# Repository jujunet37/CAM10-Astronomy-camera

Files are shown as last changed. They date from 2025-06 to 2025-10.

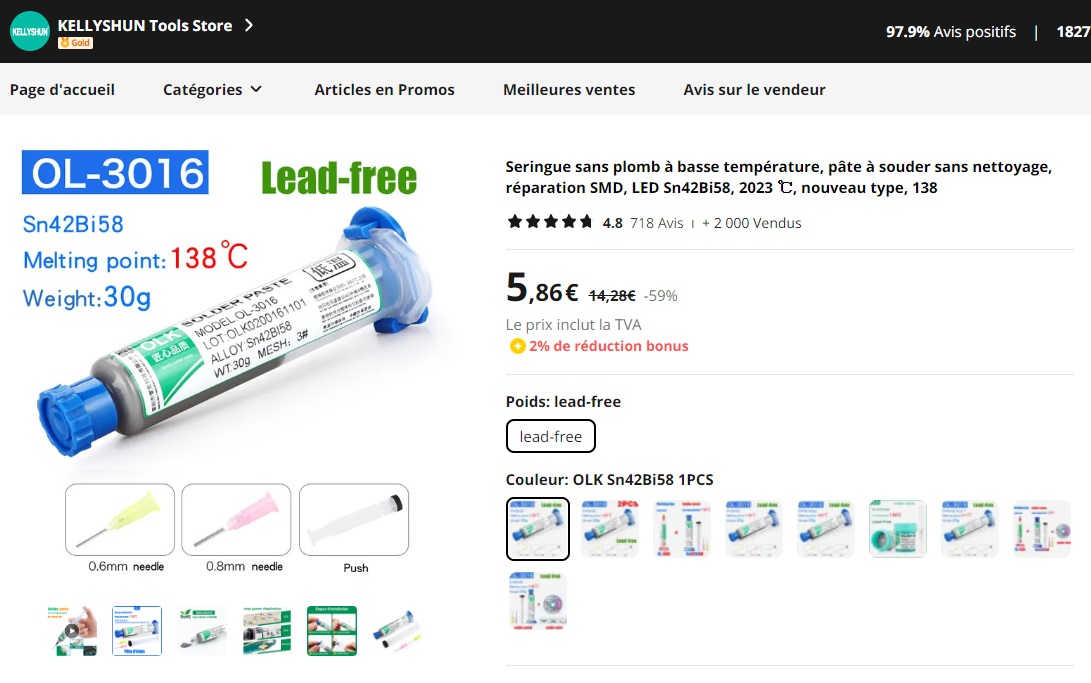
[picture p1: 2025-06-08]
Cam 10 ASCOM version/Component list/Other Stuff/Solder_paste.jpg

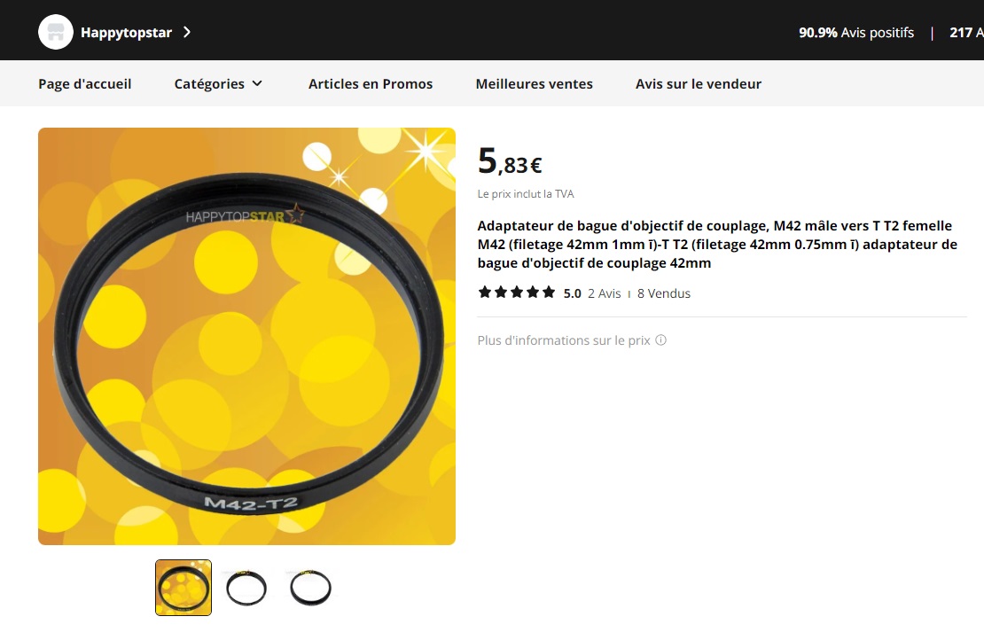
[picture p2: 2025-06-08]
Cam 10 ASCOM version/Component list/bague_M42_T2.jpg

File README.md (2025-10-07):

# CAM10-Astronomy-camera

## This repository contains all files needed to build two differents astronomy monochrome Cam10 cameras with a resolution of 1280x1024. Original wiring diagram was made by grim from Astroclub.kiev.ua.
CAUTION : For Autoguiding use the ASCOM version. The COM version is only for standalone use with the viewer.

## UPDATE 07/10/2025 :

The driver has been updated to work with PHD2. The workaround with PHD1 explained in the video is not necessary anymore. 
Driver version 0.5 didn't work because camera settings woulnd't open, and camera settings button was grayed out.
I made modifications on this driver to open the camera settings on loading. So now you can tune the image directly in PHD2.
Enjoy !

Note : I noticed my anti virus show a false positive on my mini PC (Windows Defender). It's normal with ASCOM unsigned drivers.
You can put it in white list to install if you have the message.

# Cam10 COM version :

Description : This camera can be use for planetary Imaging, there is no ASCOM driver. The viewer communicate with a virtual serial COM port. Using the pcb provided by grim I made a 3D printed enclosure for this camera. All parts needed are in the folder.

## Folders :

- Cam 10 COM Viewer : The viewer, it's a standalone viewer developped by grim to capture images on jpg, bmp, fit and ser formats. ROI capability and exposure / ISO settings. Gain/offset/delta/timer parameters.
- Components list : I provided the list of elements, with screen captures to avoid dead links, so you can easyly retrieve the parts needed.
- Firmware : The firmware and the utility to flash it on the camera (ST-LINK)
- PCB Gerber File : The Gerber file to make the PCB
- STL files Cam10 COM version : The stl files to print the enclosure

# Cam10 ASCOM version :

Description : This camera can be used for both planetary imaging and autoguiding. A viewer can be used for standalone acquisition. An ASCOM driver is provided, works with ASCOM 6.2. I used the original wiring from grim and corrected a missing track. I made a new corrected PCB with mounting holes to install a heatsink. I also made an 3D printed enclosure.

## Folders :

- ASCOM driver : This is the ascom driver to make it communicate with all astronomy softwares (Sharpcap, OpenNebulosity, PHD2). Version 0.5
- Components list : I provided the list of elements, with screen captures to avoid dead links, so you can easyly retrieve the parts needed.
- Firmware + MPROG : This is the firmware and the programming utility for flashing the FT2232 chip
- FT2232 Driver : Drivers for Windows for the FT2232. I provided 2 drivers, you can check for updates on FTDI website, type FT2232HL and install lastest drivers. WARNING : Since several years FTDI brick non genuine chips. If you purchased your chip on an official reseller, you can update to last driver. If your chip comes from Aliexpress or EBay, be careful about that, if you have any doubt, install the 2.08 provided driver.
- Old ASCOM Platform : This is the old ASCOM platform that works with this camera, not tested with newer versions.
- PCB Gerber file : The Gerber file to make the PCB
- Schema : Original diagram by grim
- STL Files CAM 10 ASCOM : The stl files to print the enclosure
- Viewer Source and Exec : Viewer souce files and main executable.

## Softwares folder : 

- This is PHD first version (very hard to found on the web). Use for the workaround to make the ascom parameter works in PHD2. Look at YouTube video link below.

Links :

Youtube tutorials :

French : https://www.youtube.com/watch?v=oHPourlEOjQ
English : https://www.youtube.com/watch?v=FNpK9c-Fqkc

Astroccd : http://astroccd.org/
Ukrainian Astropolis topic : https://www.astroclub.kiev.ua/forum/index.php?PHPSESSID=su8vh9h1n0l7lrnate4rmb50v5&topic=28929.0

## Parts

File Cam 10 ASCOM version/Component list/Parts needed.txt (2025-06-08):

Part					Number		Ref

Spring					3		Aliexpress : Honcky Shop Store 0.4mm, 10mm, 3mm 65Mn
USB cable A to B Male - Male		1		Aliexpress : QGeeM Official Store
Screw 10mmx1.6mm, washer and nut	3		Aliexpress : CLOXY Hardware Store
Copper stem 8x100			1		Aliexpress : Super 1 Store
Heatsink				1		Aliexpress : MoreSuns CustomElectronic Product Store
M42-EOS Ring				1		Aliexpress : Hension Co, Ltd Store

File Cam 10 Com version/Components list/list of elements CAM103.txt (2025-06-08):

Number	Size          	Value            Ref Farnell/Aliexpress
_____________________________________________

C1   	CAP_0603     	105   1µF  
C3   	CAP_1206     	107   100µF
C4   	CAP_1206     	107   100µF
C5   	CAP_0603     	105   1µF
C6   	CAP_0603     	105   1µF 
C7   	CAP_0603     	105   1µF  
C8   	CAP_0603     	105   1µF
C9   	CAP_0603     	105   1µF    
C31  	CAP_0603     	8p2   8.2pF           
C32  	CAP_0603     	8p2   8.2pF           
C33  	CAP_0603     	105   1µF             
C34  	CAP_0603     	105   1µF             
C36  	SIZE D       	107   100µF           
C39  	CAP_0603     	105   1µF           
R1   	RES_0603     	103   10kO           
R2   	RES_0603     	333   33kO      
R3   	RES_0603     	103   10kO         
R14  	RES_0603     	222   2.2kO      
R15  	RES_0603     	106   10MO           
R16  	RES_0603     	123   12kO  
U1   	MT9M001C12STM                 
U2   	Micro JST 1.25 3 pin
U3   	Micro JST 1.25 4 pin
U4   	TESTPOINT2   	     
U5   	STM32F446RCT6	            
U6   	LM1117-3.3   	               
U8   	USB3300      	               
Y2   	24MTSX             

Bill of mats :

Number	Size          	Value        Number    Ref Farnell/Aliexpress

C3   	CAP_1206     	107   100µF   	2	4128589      
C31  	CAP_0603     	8p2   8.2pF     2	3790636                
C33  	CAP_0603     	105   1µF       9	2112858      
C36  	SIZE D       	107   100µF     1	197348         
R1   	RES_0603     	103   10kO      2	2502926     
R2   	RES_0603     	333   33kO      1	3994549       
R14  	RES_0603     	222   2.2kO     1	3994460
R15  	RES_0603     	106   10MO	1	9238964         
R16  	RES_0603     	123   12kO 	1	2333583
U1   	MT9M001C12STM                 	1	Aliexpress : Small Li Sen Store
U2   	Micro JST 1.25 3 pin		1	Aliexpress : More Connectors Store
U3   	Micro JST 1.25 4 pin  	     	1	Aliexpress : More Connectors Store
U5   	STM32F446RCT6	            	1	Aliexpress : EC-Buying Ali Store
U6   	LM1117-3.3   	               	1	Aliexpress : Shop130245 Store
U8   	USB3300      	               	1	Aliexpress : WANXINDA Official Store
Y2   	24MTSX         			1	2853960   
USB Connector				1	3490505   
Screw 10mmx1.6mm, washer and nut	6	Aliexpress : CLOXY Hardware Store
T2 ring					1	Aliexpress : LING-SHI Store
Heatsink				1	Aliexpress : Cooltex Thermal Management Store
Glass					1	Aliexpress : SZ-TOP Store
STlink USB Key				1	Aliexpress : TENSAR ROBOT GREAT WALL Store
USB Cable A to B Male - Male		1	Aliexpress : QGeeM Offcial Store

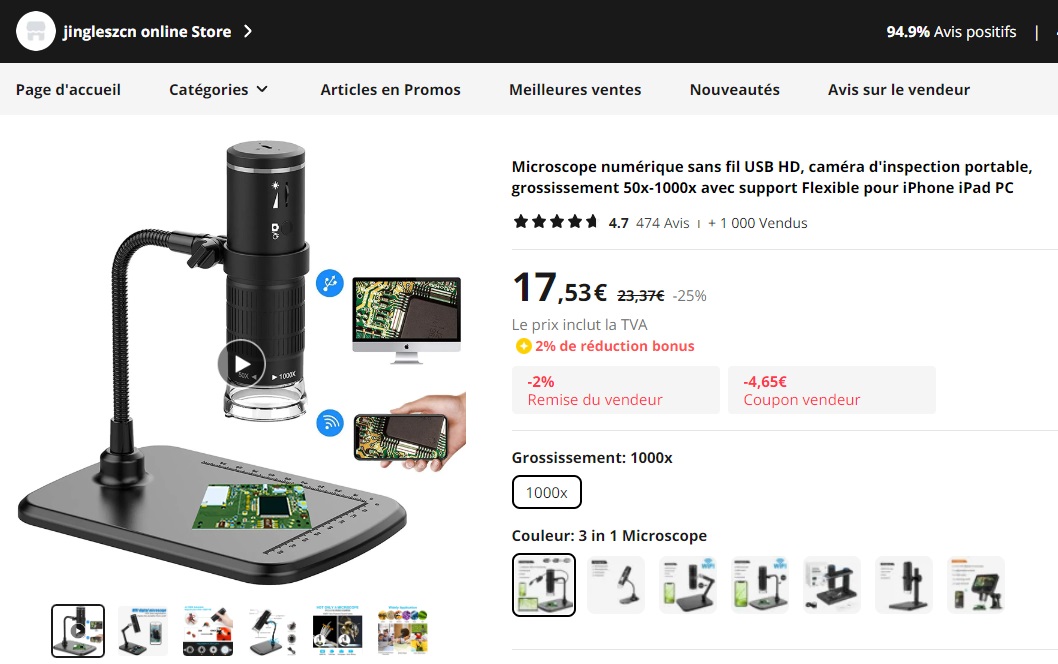
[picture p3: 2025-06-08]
Cam 10 Com version/Components list/Other Stuff/Microscope.jpg

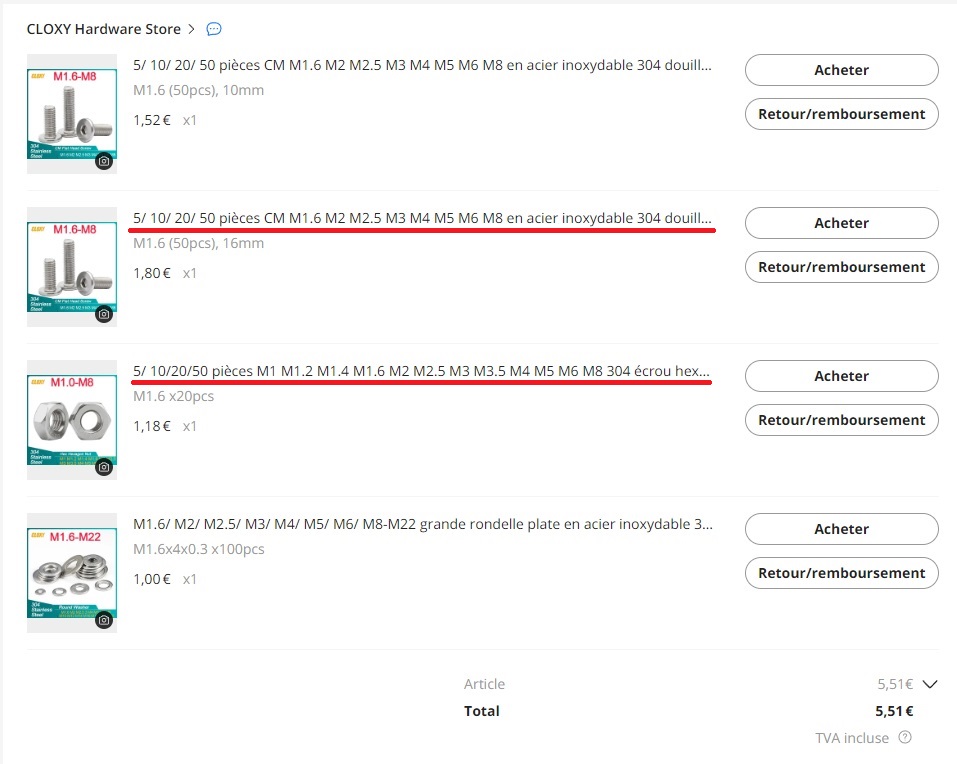
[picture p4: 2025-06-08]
Cam 10 ASCOM version/Component list/Screw ASCOM.jpg

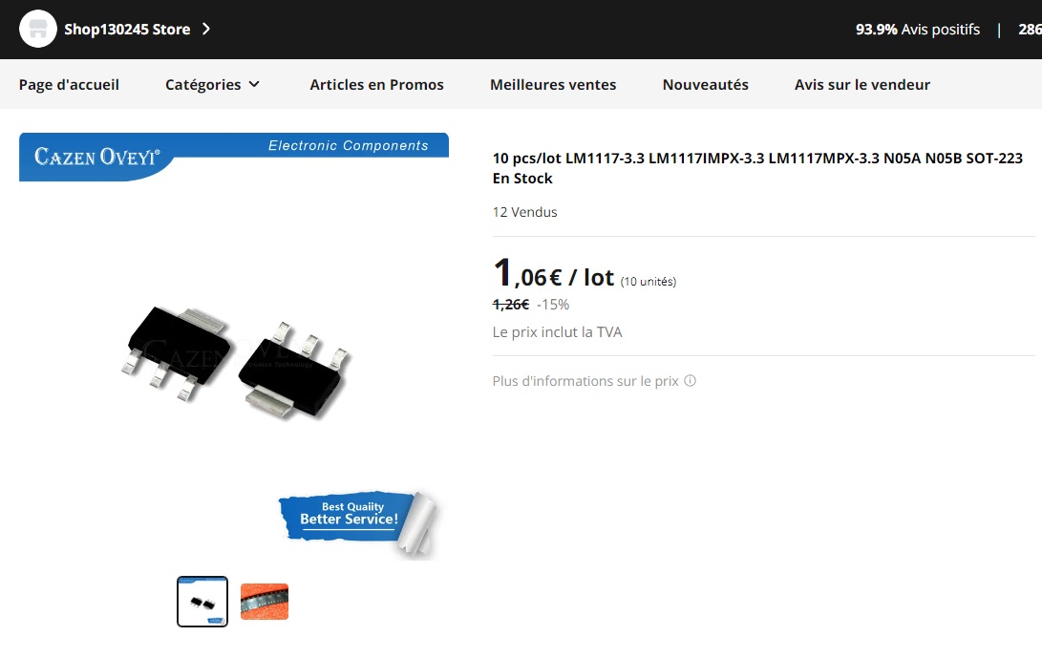
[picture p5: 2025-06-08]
Cam 10 Com version/Components list/LM1117-3.3.jpg

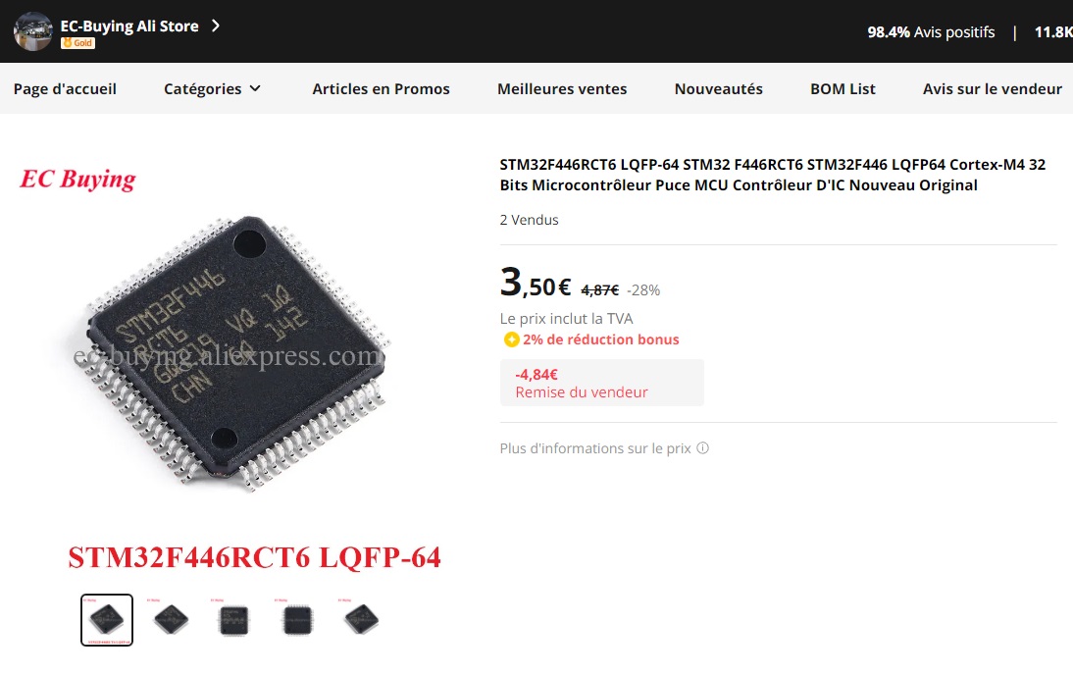
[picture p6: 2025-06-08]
Cam 10 Com version/Components list/STM32.jpg

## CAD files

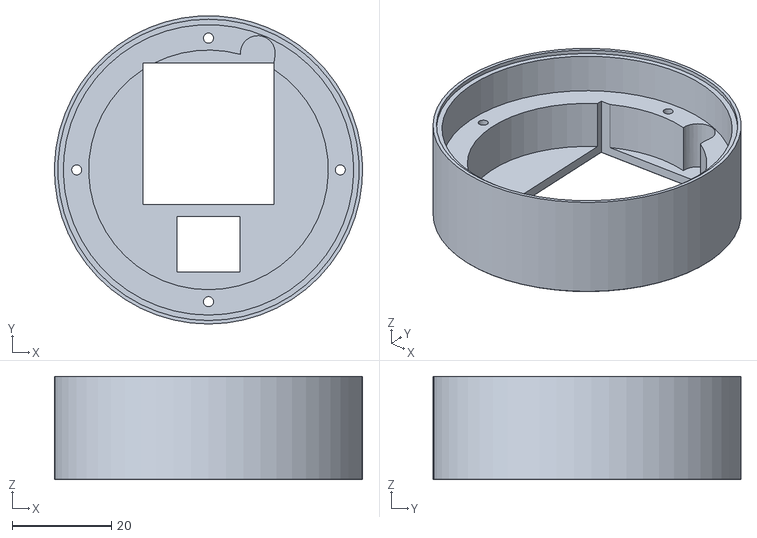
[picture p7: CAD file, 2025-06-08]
Cam 10 ASCOM version/STL Files CAM 10 ASCOM/CAM10_2-Corps.stl
62.0 x 61.9 x 20.8

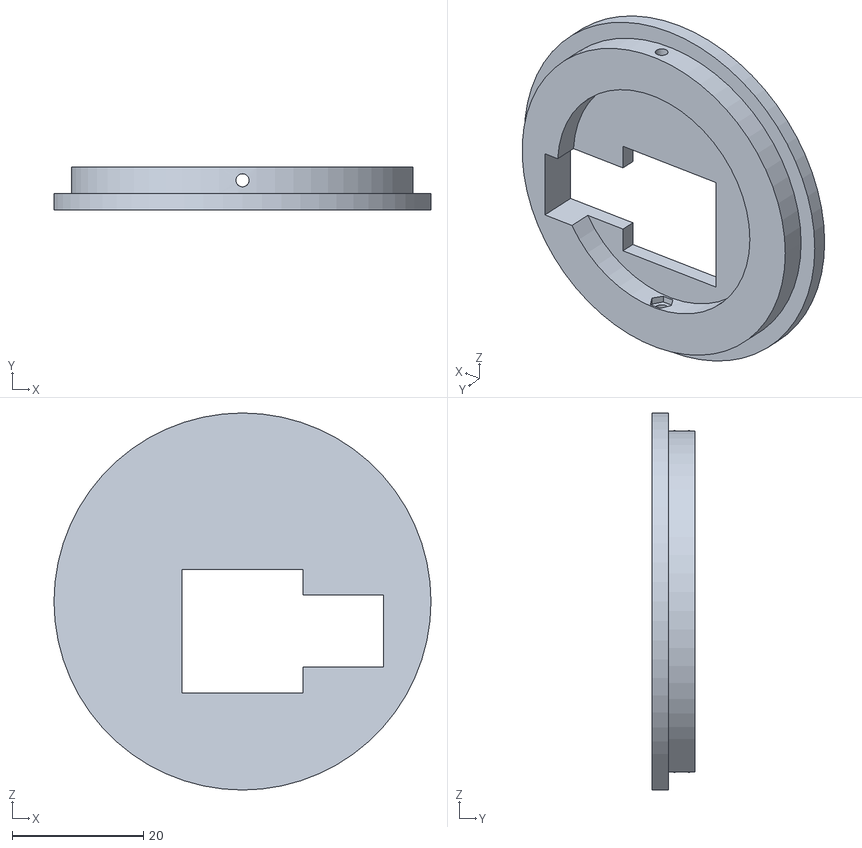
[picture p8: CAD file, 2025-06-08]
Cam 10 Com version/STL files Cam10 COM version/Cam10_ComVersion_Couvercle-Body.stl
57.4 x 6.50 x 57.4

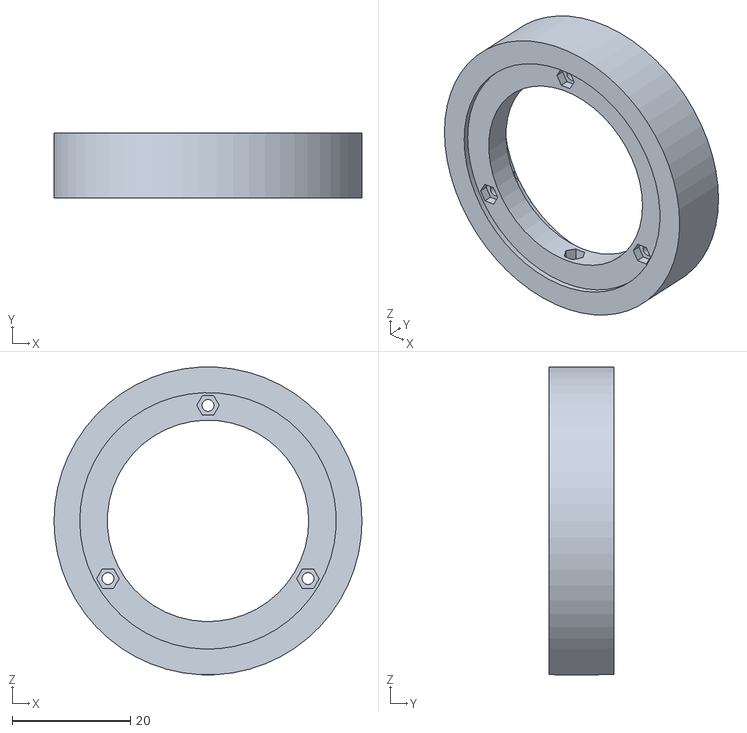
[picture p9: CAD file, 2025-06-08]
Cam 10 Com version/STL files Cam10 COM version/Cam10_ComVersion-Body.stl
52.0 x 11.0 x 52.0

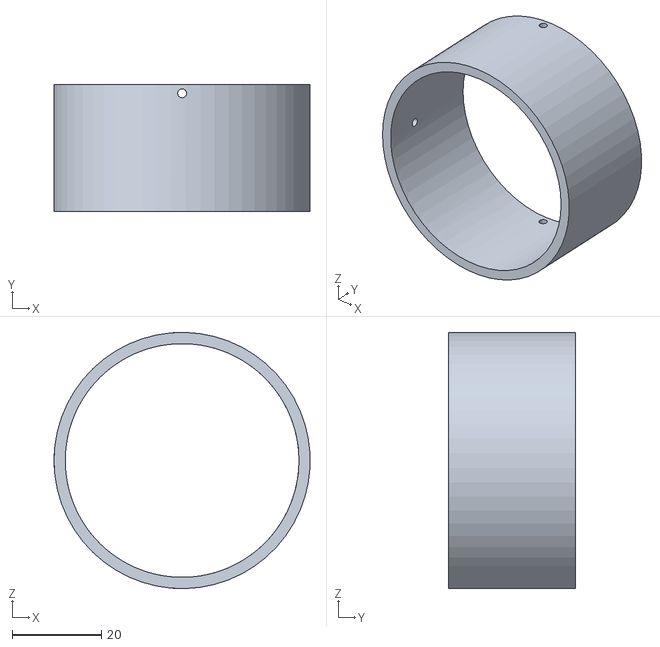
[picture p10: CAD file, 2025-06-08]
Cam 10 Com version/STL files Cam10 COM version/Cam10_ComVersion_Body-Body.stl
57.4 x 28.5 x 57.4

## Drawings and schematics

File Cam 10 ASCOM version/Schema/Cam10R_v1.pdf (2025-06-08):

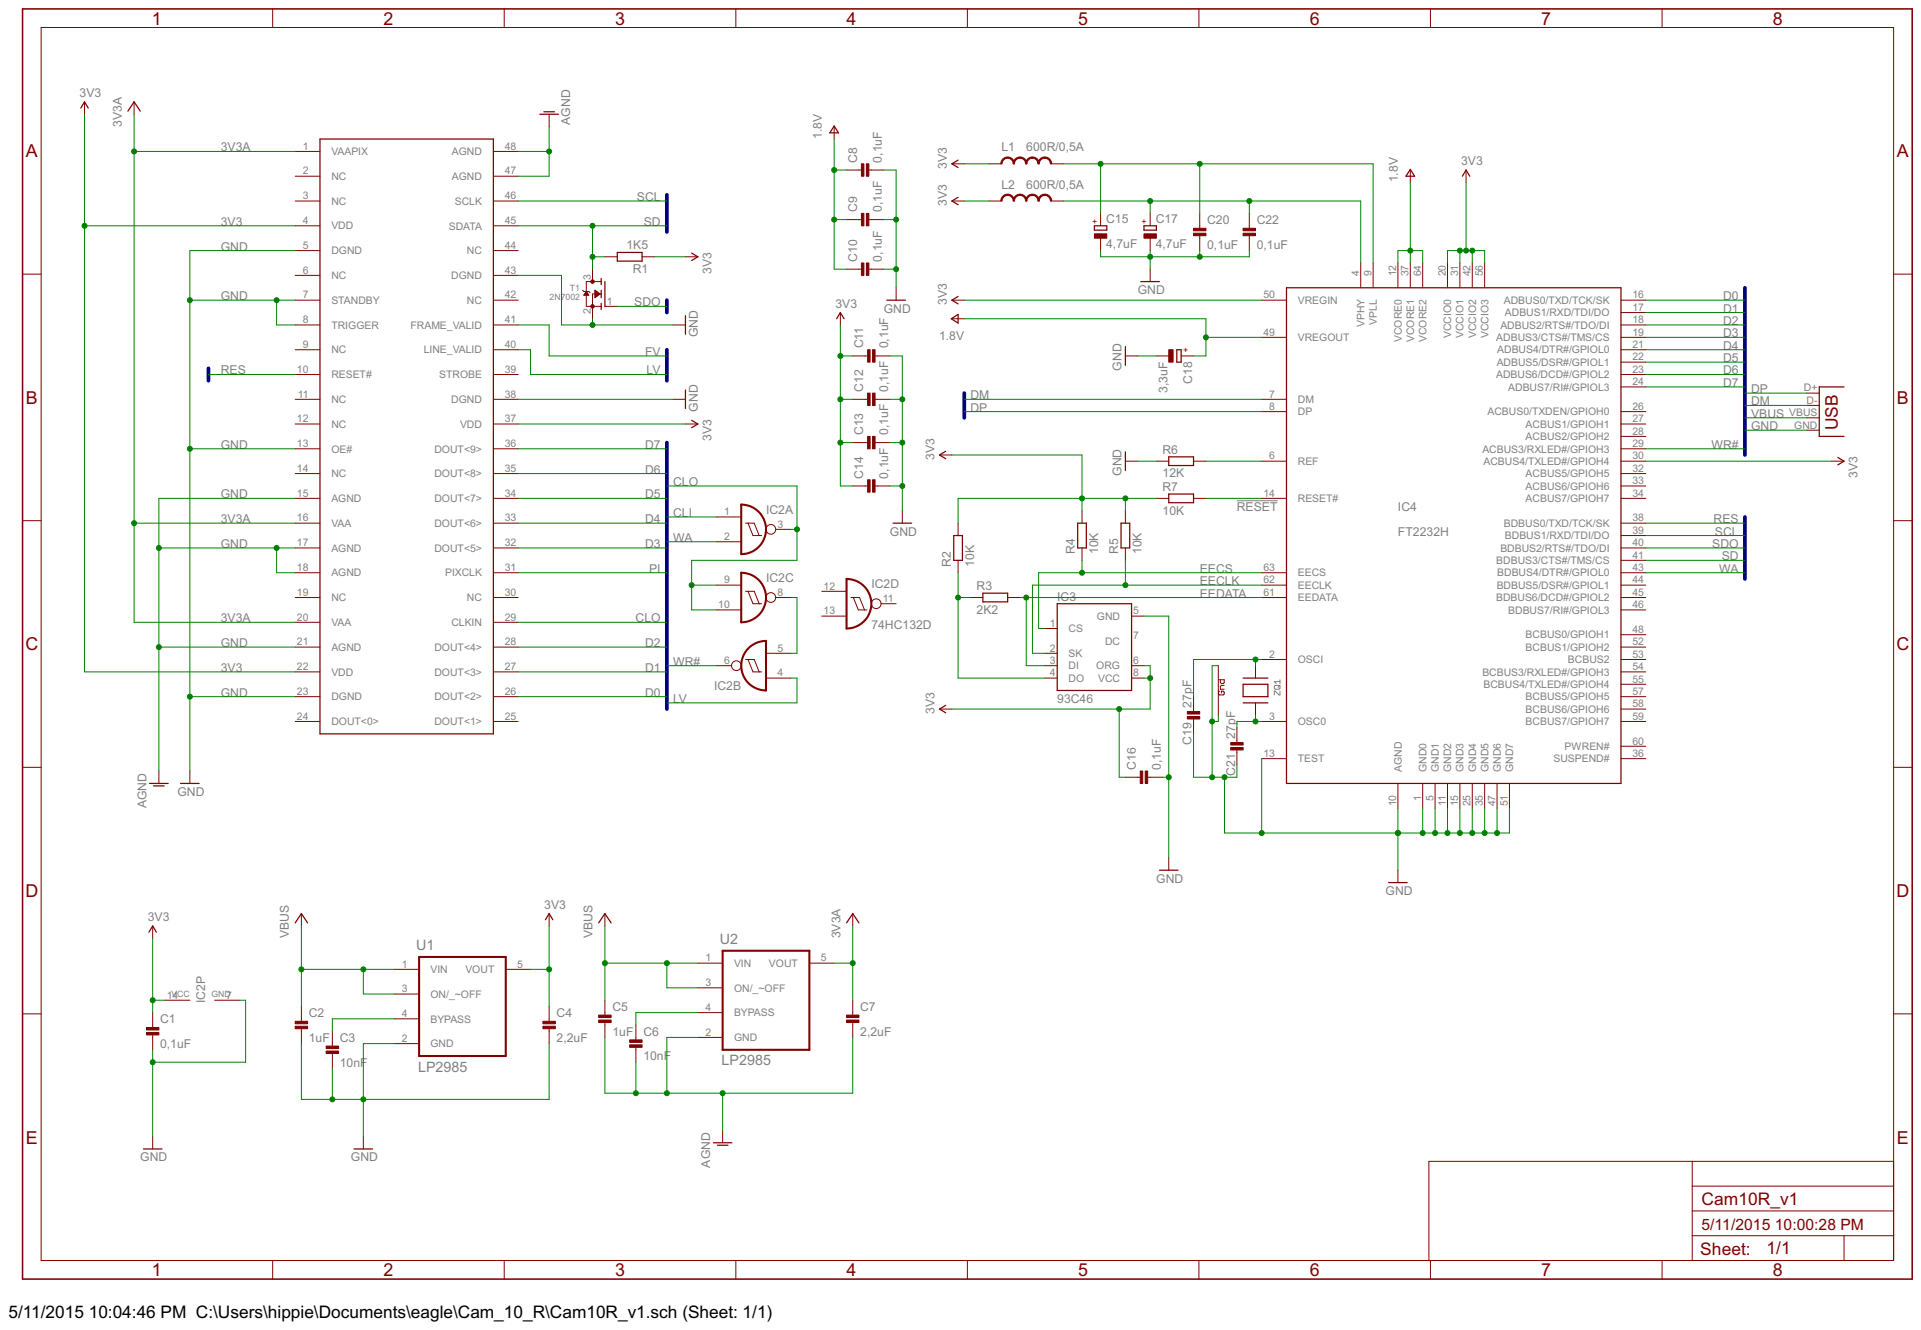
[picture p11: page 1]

GND | | 44 SDATA 43 NC

GND | 28 CLKIN D2

3V3 | 27 DOUT<4> D1

GND | 26 DOUT<3> D0

5/11/2015 10:04:46 PM C:\Users\hippie\Documents\eagle\Cam_10_R\Cam10R_v1.sch (Sheet: 1/1)
